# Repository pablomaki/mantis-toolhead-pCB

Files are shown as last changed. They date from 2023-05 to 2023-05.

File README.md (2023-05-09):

# Mantis_Toolhead_PCB

## Description

This toolhead board was designed to be used with mantis toolhead mod for voron 3D printers.

The input is 16 pin molex microfit connector and outputs include
* 1 x 2 pin microfit/JST XH connector for Heater
* 1 x 2 pin microfit/JST XH connector for Thermistor
* 1 x 2 pin microfit/JST XH connector for Hotend fan
* 1 x 2 pin microfit/JST XH connector for X-endstop
* 1 x 2 pin microfit/JST XH connector for Magprobe/Klicky/Quickdraw
* 2 x 2 pin microfit/JST XH connector for Cooling fans (connected in parallel)
* 1 x 4 pin microfit connector for Extruder motor

This PCB is simply a breakout for the inputs from 16 pin connector so the user may decide where the outputs are actually used and stray from the original designed functions of the ports.

## BOM

* PCB
* 7 x 2 pin microfit pcb headers/2 pin JST XH connectors (You can use what you like, the holes are designed for microfit connectors so hole pitch is a bit high for JST XH but should work with careful soldering, note that there is no real need for using microfits for anything other than heater for which it is recommended due to higher current.)
* 1 x 4 pin microfit pcb header (JST-XH will not work here due to too small pitch)
* 1 x 16 pin microfit pcb header horizontal or vertical.

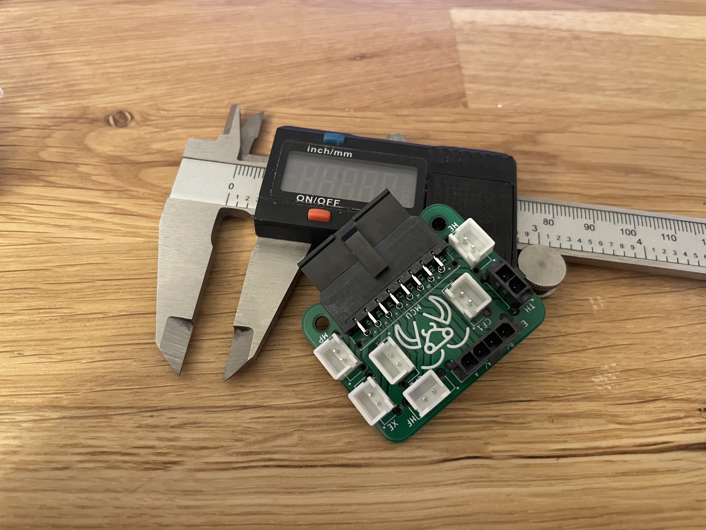
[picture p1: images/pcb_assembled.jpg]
Assembled PCB.


## Mounting

PCB can be mounted on the mantis carriage with the two m3 holes on the board as shown in the images below.

Mounted PCB.
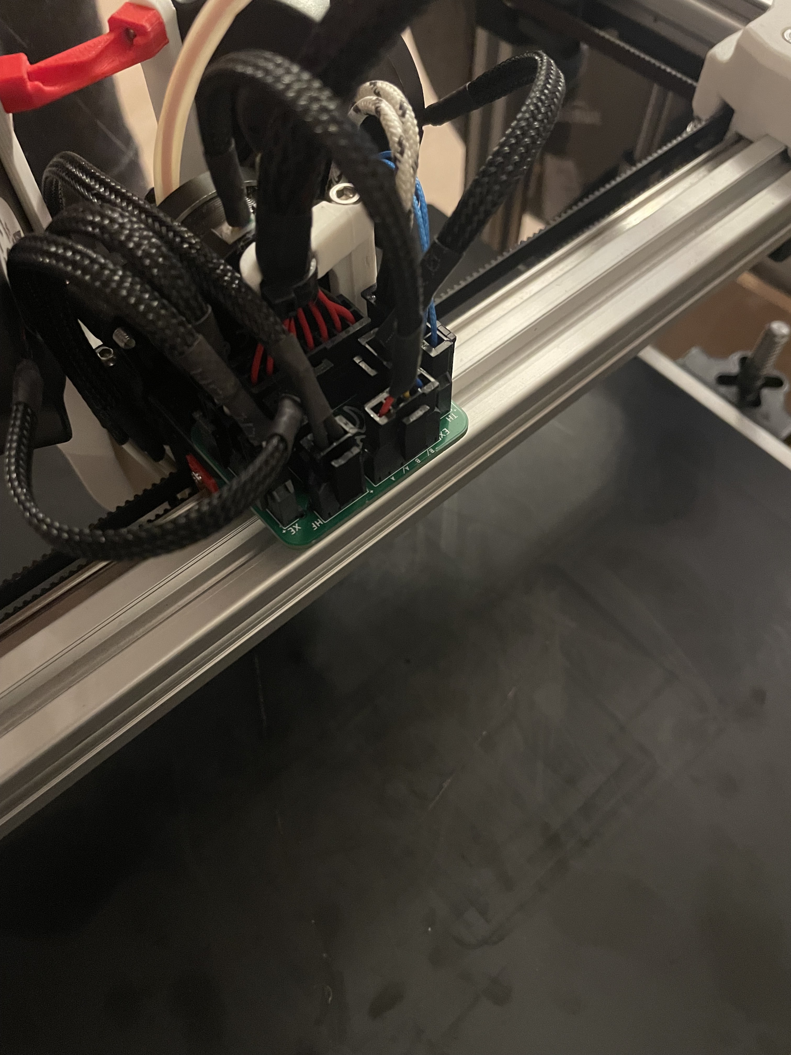
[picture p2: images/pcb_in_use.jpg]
PCB in use on a printer.


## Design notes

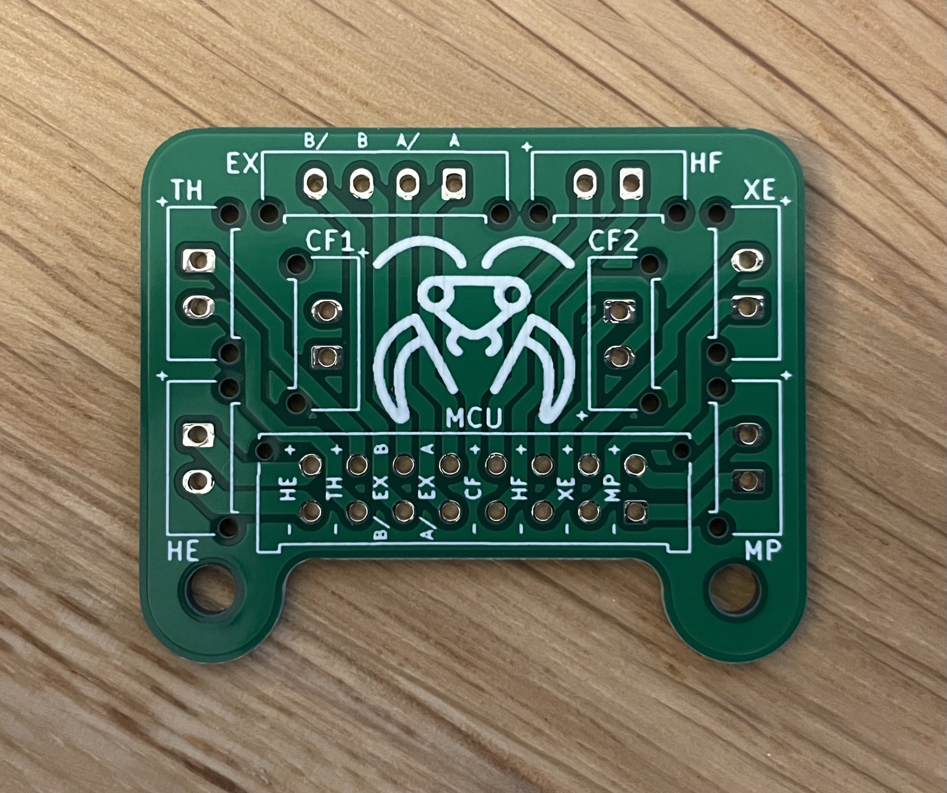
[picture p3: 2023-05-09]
images/toolhead_pcb.jpg

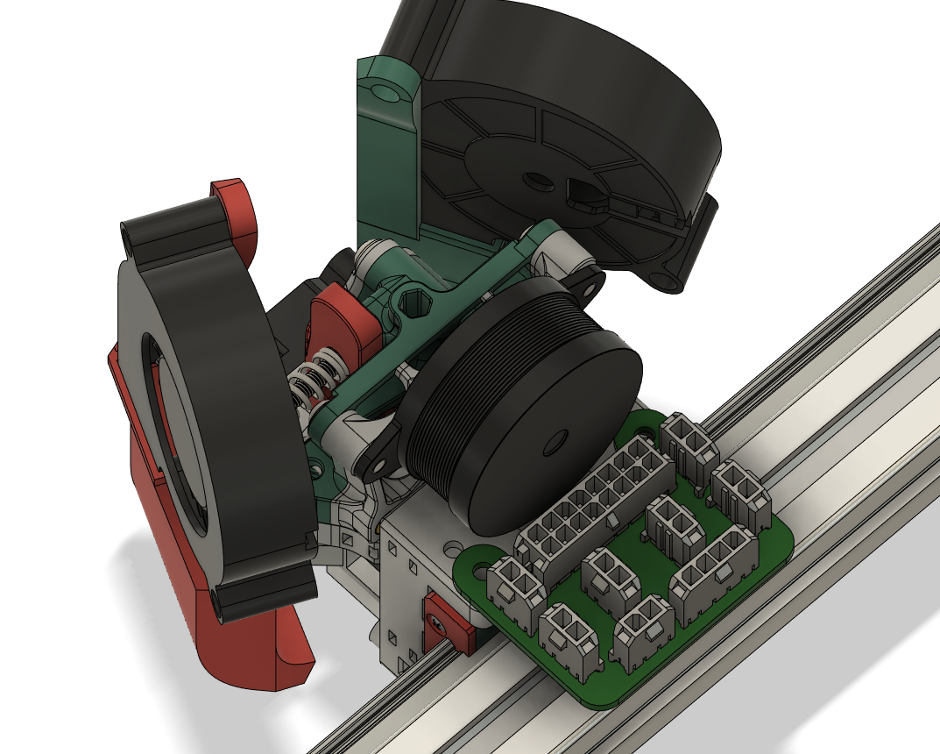
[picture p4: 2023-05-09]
images/pcb_mounted.png

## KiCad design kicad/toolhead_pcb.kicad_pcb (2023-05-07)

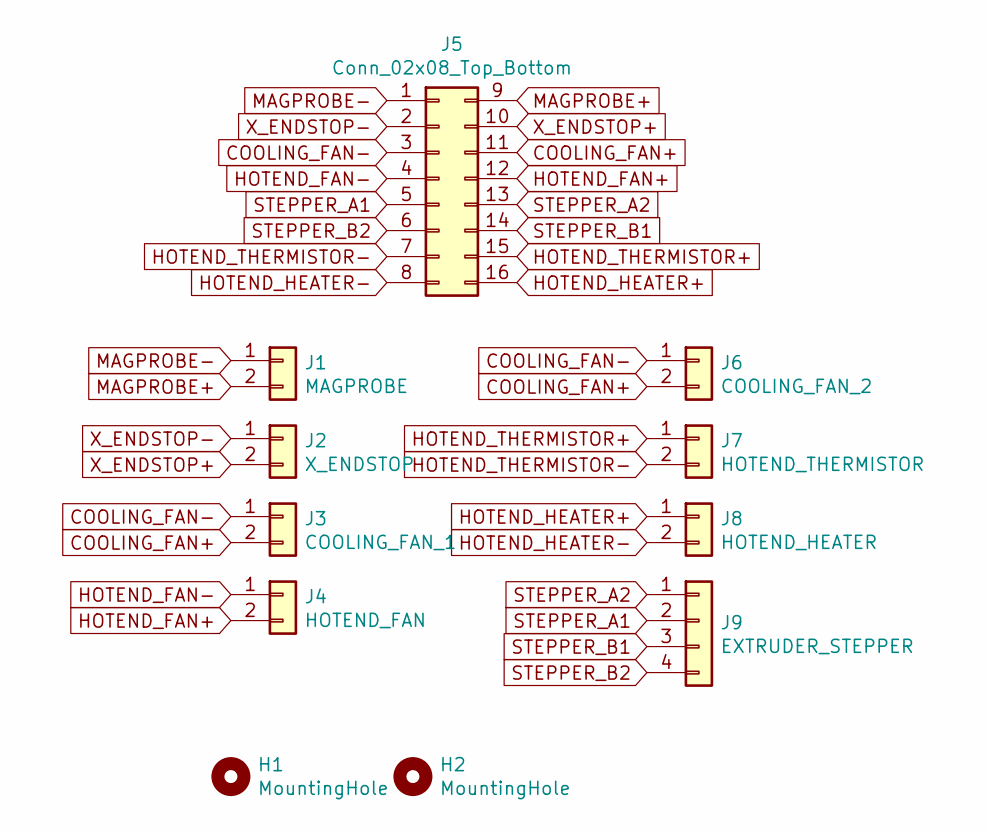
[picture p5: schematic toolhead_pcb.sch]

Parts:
H1, H2: MountingHole; MountingHole_3.2mm_M3_ISO7380
J1: MAGPROBE; Molex_Micro-Fit_3.0_43650-0215_1x02_P3.00mm_Vertical
J2: X_ENDSTOP; Molex_Micro-Fit_3.0_43650-0215_1x02_P3.00mm_Vertical
J3: COOLING_FAN_1; Molex_Micro-Fit_3.0_43650-0215_1x02_P3.00mm_Vertical
J4: HOTEND_FAN; Molex_Micro-Fit_3.0_43650-0215_1x02_P3.00mm_Vertical
J5: Conn_02x08_Top_Bottom; Molex_Micro-Fit_3.0_43045-1612_2x08_P3.00mm_Vertical
J6: COOLING_FAN_2; Molex_Micro-Fit_3.0_43650-0215_1x02_P3.00mm_Vertical
J7: HOTEND_THERMISTOR; Molex_Micro-Fit_3.0_43650-0215_1x02_P3.00mm_Vertical
J8: HOTEND_HEATER; Molex_Micro-Fit_3.0_43650-0215_1x02_P3.00mm_Vertical
J9: EXTRUDER_STEPPER; Molex_Micro-Fit_3.0_43650-0415_1x04_P3.00mm_Vertical

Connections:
COOLING_FAN+: J3.2, J5.11, J6.2
COOLING_FAN-: J3.1, J5.3, J6.1
HOTEND_FAN+: J4.2, J5.12
HOTEND_FAN-: J4.1, J5.4
HOTEND_HEATER+: J5.16, J8.1
HOTEND_HEATER-: J5.8, J8.2
HOTEND_THERMISTOR+: J5.15, J7.1
HOTEND_THERMISTOR-: J5.7, J7.2
MAGPROBE+: J1.2, J5.9
MAGPROBE-: J1.1, J5.1
STEPPER_A1: J5.5, J9.2
STEPPER_A2: J5.13, J9.1
STEPPER_B1: J5.14, J9.3
STEPPER_B2: J5.6, J9.4
X_ENDSTOP+: J2.2, J5.10
X_ENDSTOP-: J2.1, J5.2

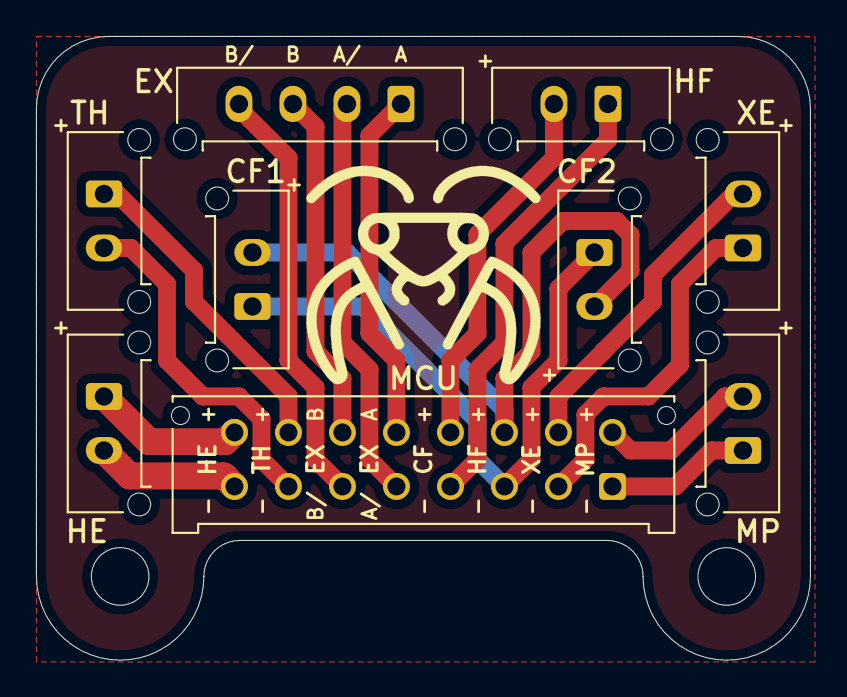
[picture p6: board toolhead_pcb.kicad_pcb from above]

Board: 2 copper layers, 43.0 x 34.7 mm, 11 parts (0 on the bottom side), 16 nets.

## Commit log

2023-05-07 Initial push of exiting stuff
    [toolhead_pcb-B_Cu.gbr, toolhead_pcb-B_Mask.gbr, toolhead_pcb-B_Paste.gbr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]
2023-05-09 Organize and add content to README
    [toolhead_pcb.kicad_pcb, toolhead_pcb.sch]
